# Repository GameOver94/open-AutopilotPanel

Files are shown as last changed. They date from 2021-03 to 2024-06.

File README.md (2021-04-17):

# open AutopilotPanel
A 3D printable autopilot panel for Microsoft Flightsimulator modeled after the Garmin GFC 500

## Features
* 3 Rotary Encoder (HDG / ALT / VS up/down)
* 12 Pushbuttons
* Emulates a standard gamecontroller (no additional software needed)

## Uses Materials
 * 1 [Arduino Pro Micro](https://www.amazon.de/gp/product/B07J2Q3ZD5/ref=ppx_yo_dt_b_asin_title_o03_s00?ie=UTF8&psc=1)
 * 1 [MCP23017 I²C Port Expander](https://eu.mouser.com/ProductDetail/Microchip-Technology/MCP23017-E-SO?qs=usxtMOJb1Rz8hft7vV7YMQ==)
   * Make shure to get the MCP23017-E/SO variant. There are other footpirnts of the chip available. For hand wiring get a bearkout board to make live easier.
 * 3 [Rotary Encoder](https://www.amazon.de/gp/product/B08728PS6N/ref=ppx_yo_dt_b_asin_title_o01_s00?ie=UTF8&psc=1)
 * 12 [Miro Pushbuttons 6x6x5](https://www.amazon.de/gp/product/B07Q1BXV7T/ref=ppx_yo_dt_b_asin_title_o04_s00?ie=UTF8&psc=1)
 * 26 AWG silicone wire
 * Dupont connectors
 * Double sided tape

## Important Note
This is for people who build this before version 1.1.0. The wiring has changed a bit with regard to the previous versions. Mainly the switches of the rotary enocders are now also connected to the MCP23017 and the rotary encoders are now connected to slightly different pins. Therefor the current software won't fully work. I think it's pretty easy to rewire these connections if you want, but I also created a [legacy branch](https://github.com/GameOver94/open-AutopilotPanel/tree/legacy) where you download the old firmware.
## Assembly
The mechaical design was done in Fusion 360. The assemby files can be found in [CAD files](CAD%20files) as .f3z and .step files. STL files for direct 3D Printing can be found on [Thiniverse](https://www.thingiverse.com/thing:4799181).

The electrical design was made with EasyEDA. The files for the PCB can either be found in the folder [PCB files](PCB%20files) or you can order them directly here: https://oshwlab.com/patrick.harrer94/open-autopilot

A [wiring diagram](PCB%20files/Schematic_open-AutopilotPanel.pdf) for the connection between the arduino and the PCB or for manual wiring can be also found in the PCB fiels folder.

### PCB Assembly
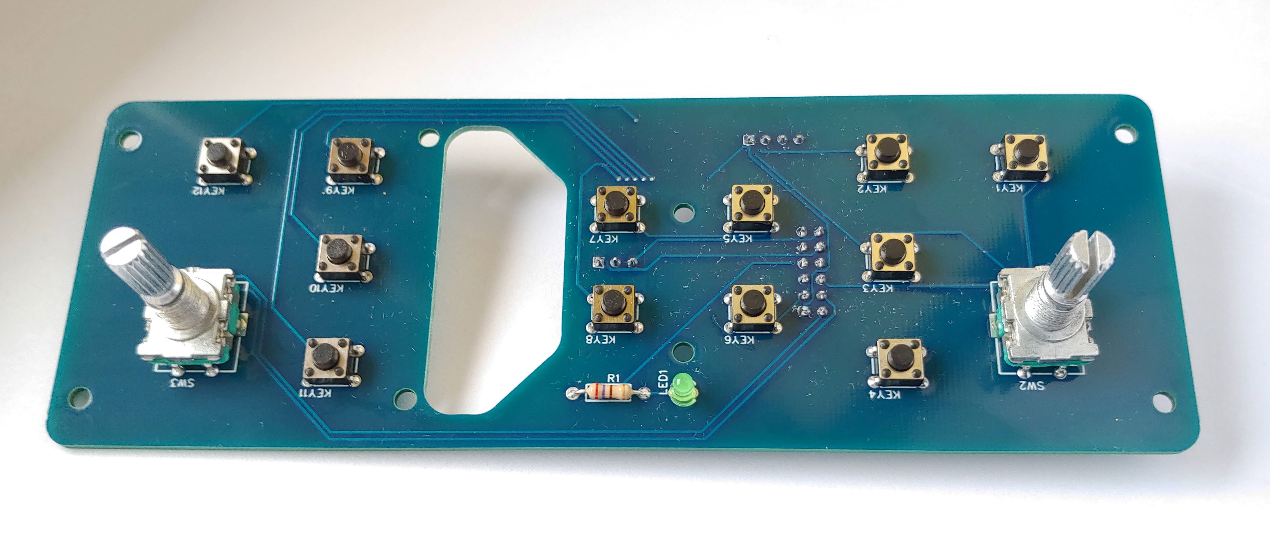
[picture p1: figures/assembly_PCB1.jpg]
image_PCB1

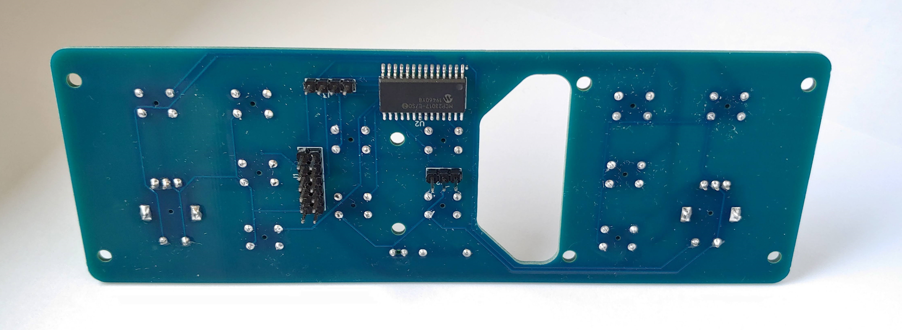
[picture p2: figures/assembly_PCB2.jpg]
image_PCB2

### Electronic Assembly
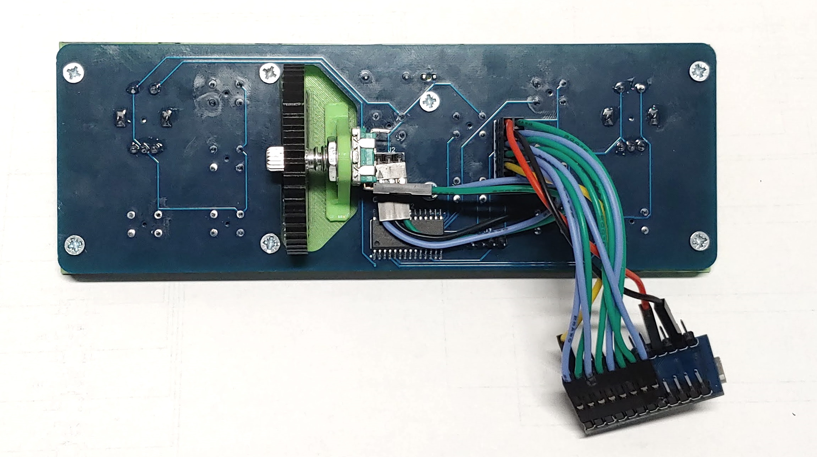
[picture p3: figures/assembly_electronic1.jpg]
image_electornic1

### Whole Assembly
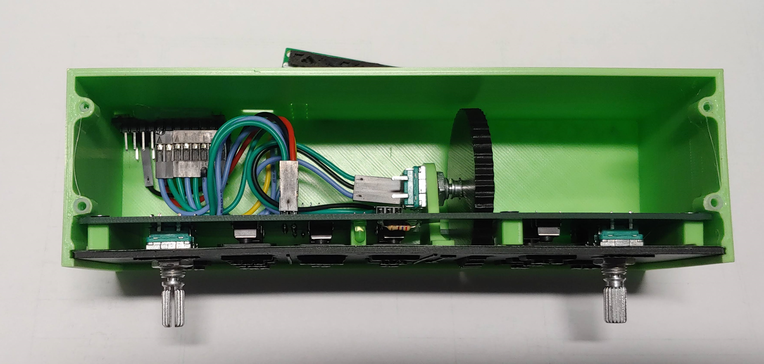
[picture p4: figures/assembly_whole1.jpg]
image_assemby1

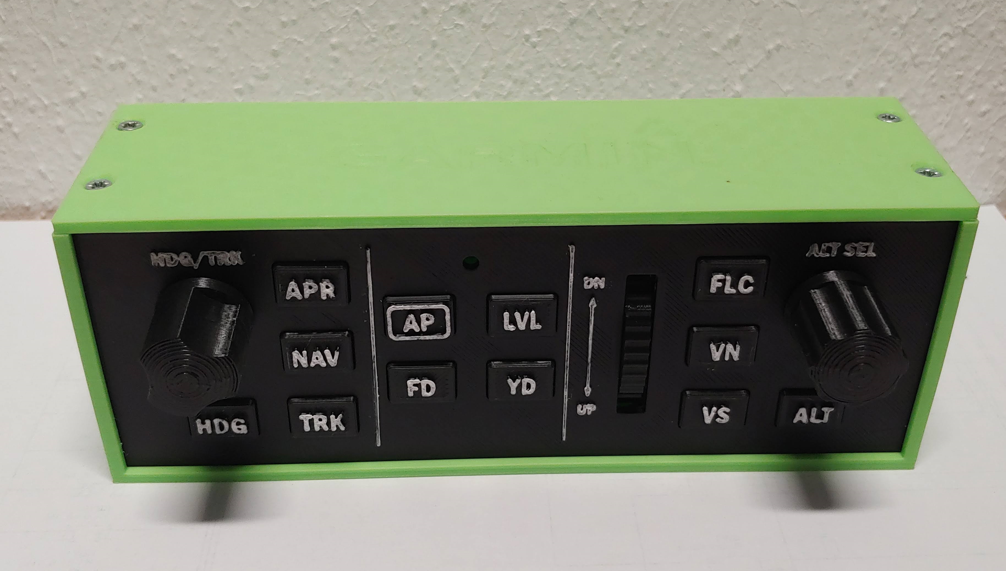
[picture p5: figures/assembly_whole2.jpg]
image_assembly2

### Manual Wireing
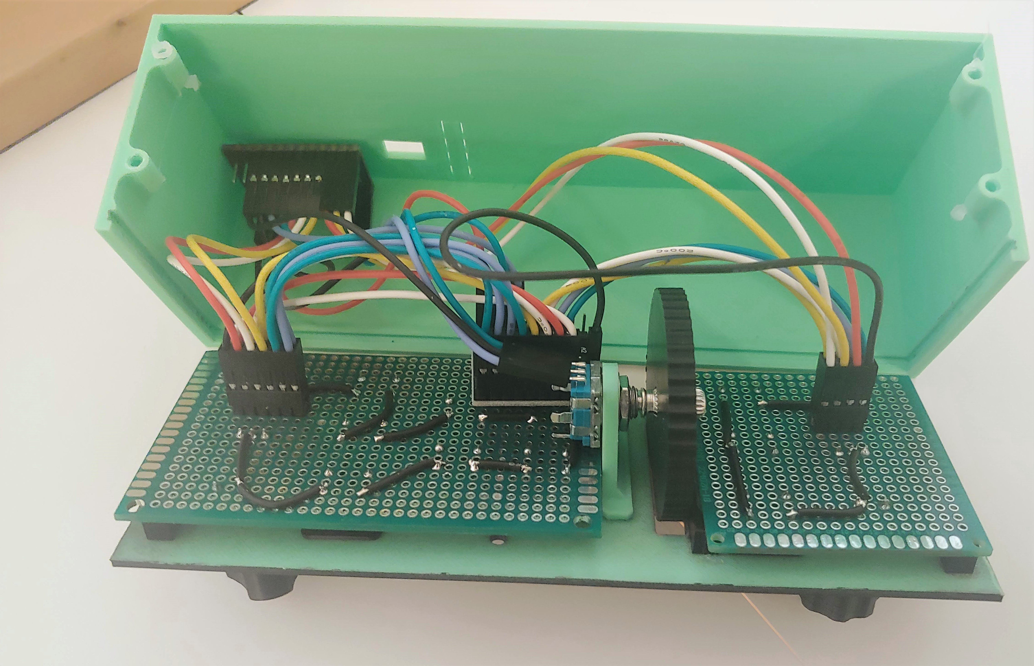
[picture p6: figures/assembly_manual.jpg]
image_assembly3


## Cangelog

### v1.0.0
* Initial release
### v1.0.1
* Tweaks regarding button press timings
### v1.1.0
* Added a PCB design
* Modified software for wiring
  * The buttons in the rotary encoders are now also connected to the MCP23017
  * Added a power LED
## ToDo
* Maybe a version 2 with an added lcd to show AP mode, set altitude usw. (requires software running on the PC)

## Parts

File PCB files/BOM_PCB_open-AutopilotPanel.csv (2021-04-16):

ID | Name | Designator | Footprint | Quantity | Manufacturer Part | Manufacturer | Supplier | Supplier Part | Price | JLCPCB SMD | Paste Type
1 | HDR-M-2.54_2x6 | J1 | HDR-M-2.54_2X6 | 1 |  |  | LCSC | C124388 | 0.0628
2 | HDR-M-2.54_1x3 | J2 | HDR-M-2.54_1X3 | 1 |  |  | LCSC | C180248 | 0.2066
3 | HDR-M-2.54_1x4 | J3 | HDR-M-2.54_1X4 | 1 |  |  | LCSC | C124378 | 0.0261
4 | K4-6×6_TH | KEY1,KEY2,KEY3,KEY4,KEY5,KEY6,KEY7,KEY8,KEY9,KEY10,KEY11,KEY12 | KEY-TH_4P-L6.0-W6.0-P4.50-LS6.5 | 12 | K2-1102DP-E4SW-04 | 韩国韩荣 | LCSC | C136684 | 0.0365
5 | LED-TH-3mm_B | LED1 | LED-TH_BD3.0_BLUE | 1 | 204-10SUBC/S400-A4 | EVERLIGHT(台湾亿光) | LCSC | C86881 | 0.0476
6 | 500Ω | R1 | R_AXIAL-0.4 | 1
7 | Rotary switch | SW2,SW3 | SW7-13.75X11.7X6.5MM | 2 | Rotary switch
8 | MCP23017-E/SO | U2 | SOIC-28_L18.1-W10.3-P1.27-LS10.3-BL | 1 | MCP23017-E/SO | MICROCHIP | LCSC | C47023 | 1.3407 | Yes | recommend

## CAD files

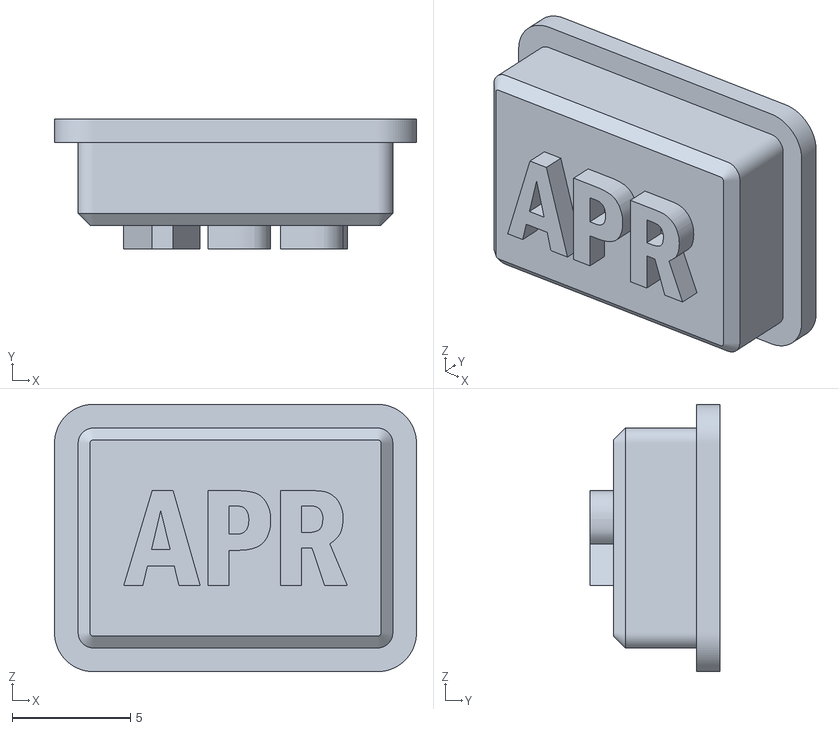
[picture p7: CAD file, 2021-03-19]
3D printing files/Button_Autopilot v12_Körper10_Button.stl
15.3 x 5.50 x 11.3

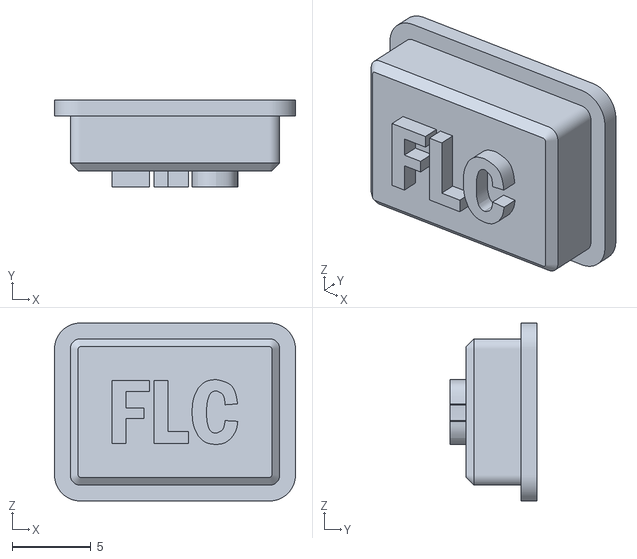
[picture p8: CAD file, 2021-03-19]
3D printing files/Button_Autopilot v12_Körper7_Button.stl
15.3 x 5.50 x 11.3

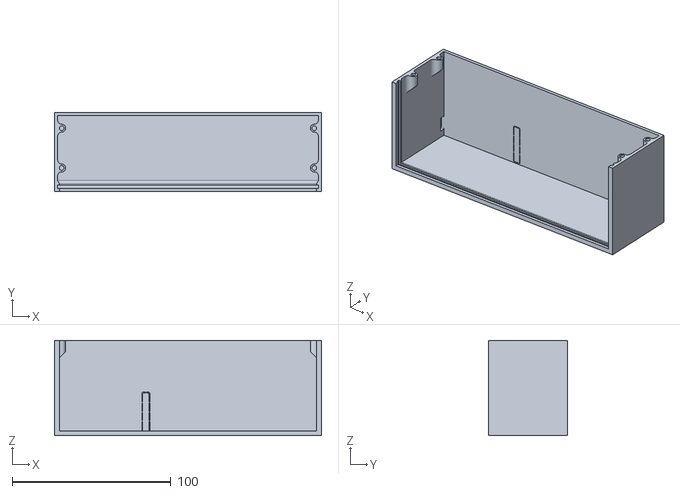
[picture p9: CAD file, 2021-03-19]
3D printing files/Case.stl
168.0 x 50.0 x 60.0

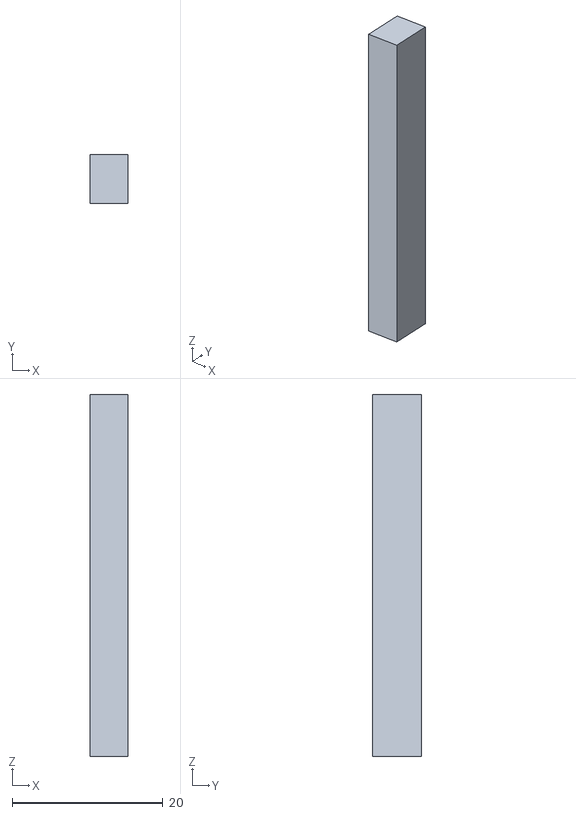
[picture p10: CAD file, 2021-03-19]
3D printing files/PCB Spacer 4.stl
5.00 x 6.50 x 48.0

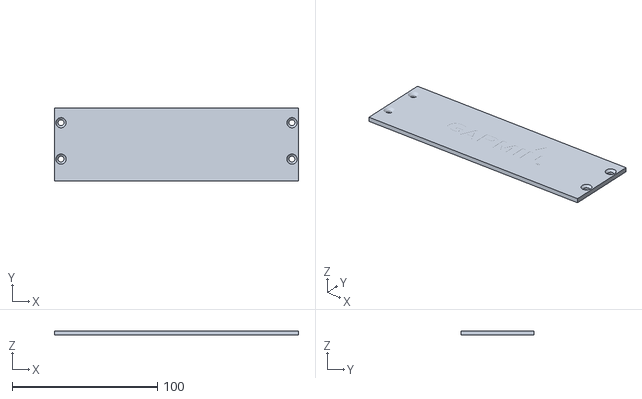
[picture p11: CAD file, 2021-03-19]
3D printing files/Case Cover.stl
168.0 x 50.0 x 3.00

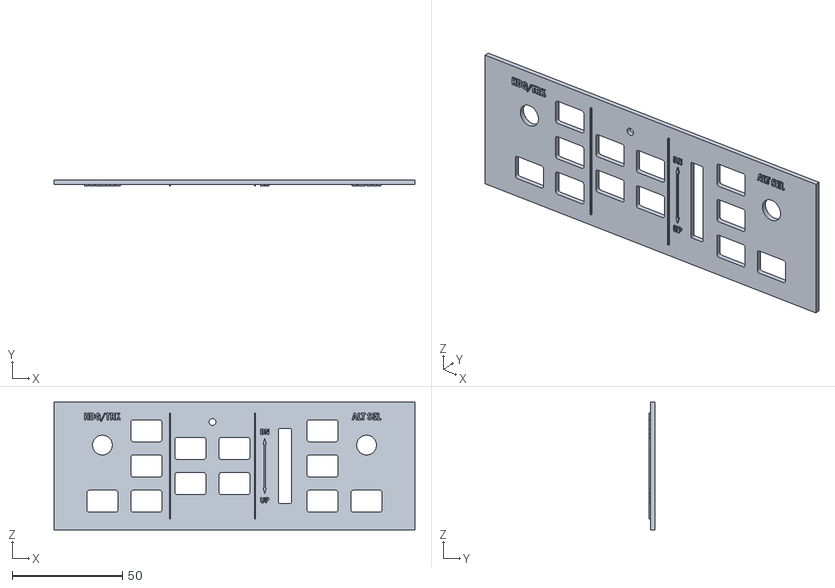
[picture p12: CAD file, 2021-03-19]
3D printing files/Faceplate.stl
164.0 x 2.60 x 58.0

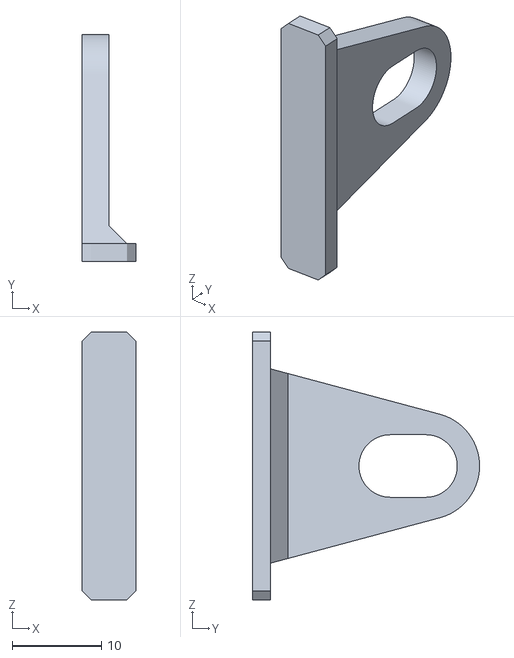
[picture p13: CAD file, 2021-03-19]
3D printing files/Wheel Holder.stl
6.00 x 25.4 x 30.0

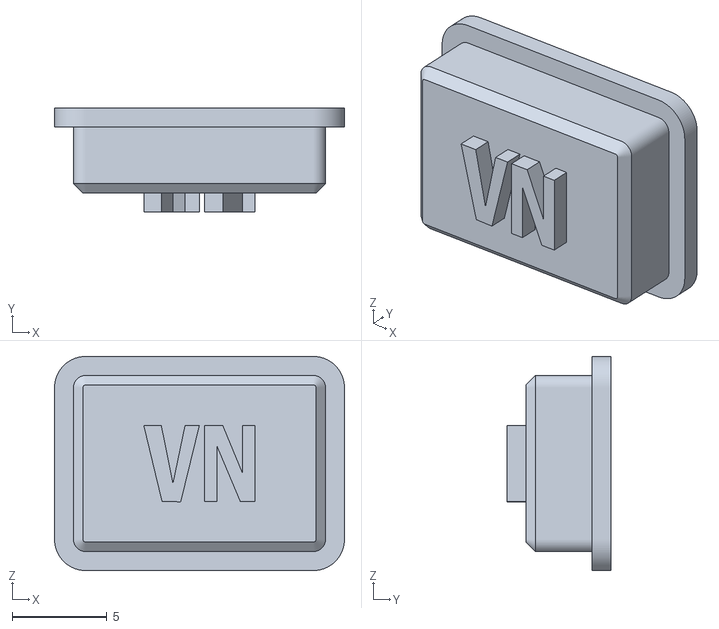
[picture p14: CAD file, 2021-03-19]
3D printing files/Button_Autopilot v12_Körper1_Button.stl
15.3 x 5.50 x 11.3

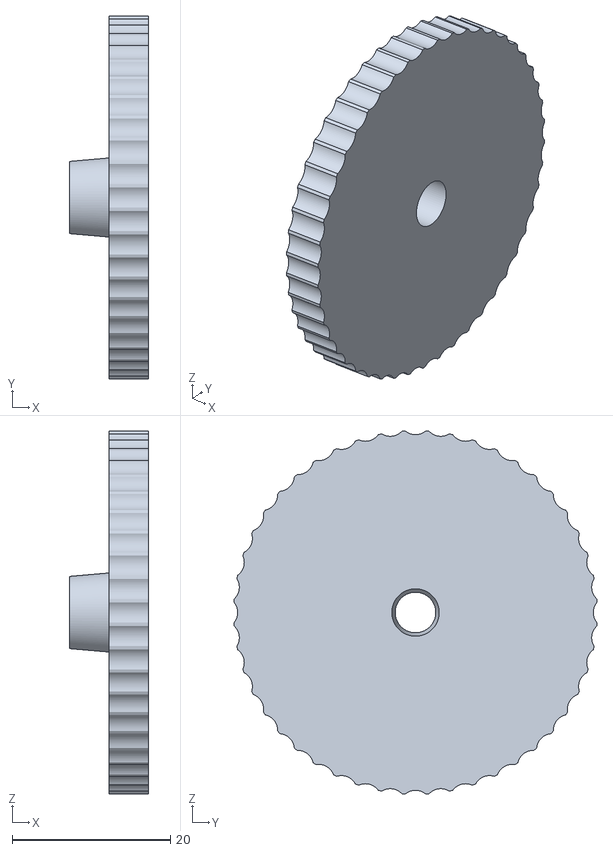
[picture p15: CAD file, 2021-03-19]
3D printing files/Wheel.stl
10.0 x 45.9 x 45.9

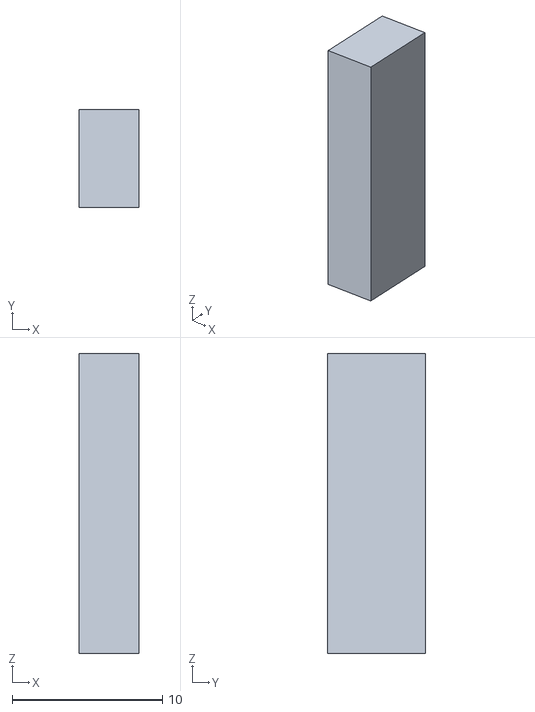
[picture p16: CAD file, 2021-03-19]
3D printing files/PCB Spacer 2.stl
4.00 x 6.50 x 20.0

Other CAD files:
3D printing files/Button_Autopilot v12_Körper9_Button.stl
3D printing files/PCB Spacer 1.stl
3D printing files/Button_Autopilot v12_Körper12_Button.stl
3D printing files/Button_Autopilot v12_Körper6_Button.stl
3D printing files/Button_Autopilot v12_Körper2_Button.stl
3D printing files/PCB Spacer 3.stl
3D printing files/Button_Autopilot v12_Körper3_Button.stl
3D printing files/Button_Autopilot v12_Körper11_Button.stl
3D printing files/Button_Autopilot v12_Körper4_Button.stl
3D printing files/Button_Autopilot v12_Körper5_Button.stl
3D printing files/Button_Autopilot v12_Körper8_Button.stl
3D printing files/Knob 3 Slot.stl
3D printing files/Knob 8 Slot.stl
CAD files/Autopilot v21.f3z

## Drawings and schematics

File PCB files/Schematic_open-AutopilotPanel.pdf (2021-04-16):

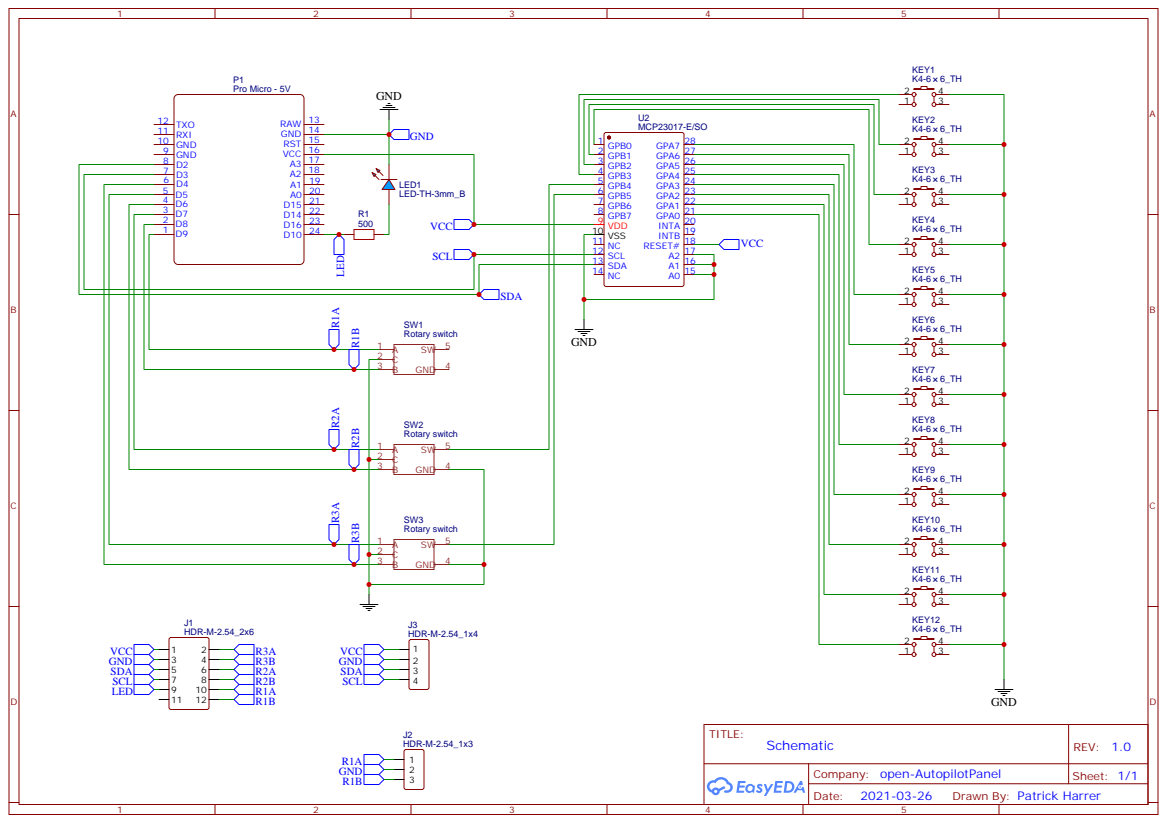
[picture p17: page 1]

Drawn By: Patrick Harrer

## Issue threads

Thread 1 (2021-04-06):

suggestion: led indication of ap mode

medoh300, 2021-04-06:
as on the real thing , one could have a led indicating which AP mode is selected :

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

a video of the real thing in action:

https://www.youtube.com/watch?v=TLRn8gpOxv0

GameOver94, 2021-04-07:
I think currently it won't be possible because it will get synchronized. To do this an application has to run on the PC and hook into the flight sim and send back state of autopilot.

Additionally this will almost double the pins needed. I'm currently designing a PCB and to fit a second MCP23017 the push buttons and LEDs have to be surface mount components.

In the future I'm planing a version 2 which communicates via SimConnect. There I might consider this again but this will take a while.

medoh300, 2021-04-07:
would it be possible with mobiflight and logic for lights maybe ?

GameOver94, 2021-04-08:
I'm not very familiar with mobiflight but I think it might be possible but as far as I can tell the mobiflight firmware doesn't support the MCP23017 so the firmware has to be modified.

Closed 2021-06-22.

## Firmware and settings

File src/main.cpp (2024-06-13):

#include <Arduino.h>
#include <Wire.h>
#include <Adafruit_MCP23X17.h>
#include <Rotary.h>
#include <Joystick.h>

// Pin Mapping --------------------------------------------------------------------------------
#define HDG 11    // Key 1
#define TRK 10    // Key 2
#define NAV 9     // Key 3
#define APR 8     // Key 4
#define FD 7      // Key 5
#define AP 6      // Key 6
#define YD 5      // Key 7
#define LVL 4     // Key 8
#define VS 3      // Key 9
#define VN 2      // Key 10
#define FLC 1     // Key 11
#define ALT 0     // Key 12

#define rotHDGButton 12     // SW2
#define rotALTButton 13     // SW3

#define rotHDG_A 6     // SW2
#define rotHDG_B 7     // SW2

#define rotALT_A 5     // SW3
#define rotALT_B 4     // SW3

#define rotVS_A 8 // SW1
#define rotVS_B 9 // SW1

#define pwrLED 10

// Function prototypes ------------------------------------------------------------------------
void pollButton();
void pollRotary();
void updateButton(bool buttonState[16]);
void release();

// Setup the joystick library -----------------------------------------------------------------
/* Create the Joystick */
Joystick_ Joystick;

/* Joystick Button Mapping
rotary HDG right      0
rotary HDG left       1
rotary ALT right      2
rotary ALT left       3
rotary VS up          4
rotary VS down        5

button ALT            6
button AP             12
button APR            14
button FD             13
button FLC            7
button HDG            17
button LVL            10
button NAV            15
button TRK            16
button VN             8
button VS             9
button YD             11
rotary ALT            19
rotary HDG            18
*/

// Setup the MCP23017 GPIO expander -----------------------------------------------------------
Adafruit_MCP23X17 mcp;

// Setup rotary encoder------------------------------------------------------------------------
Rotary rotHDG = Rotary(rotHDG_A, rotHDG_B);
Rotary rotALT = Rotary(rotALT_A, rotALT_B);
Rotary rotVS = Rotary(rotVS_A, rotVS_B);

// Global variables
const uint8_t numRotary = 6;            // For each rotary encoder two (one per direction)
unsigned long releaseTime[numRotary];    // Stores the release time for the buttons (rotary encoder).
bool rotaryPressed[numRotary] = {false}; // Stores the button state for the rotary encoder (gets automatically reset)
const int rotaryHoldTime = 50;           // time a Button is held down in ms (rotary encoder)
const int buttonHoldTime = 100;          // time a Button is held down in ms (buttons)
uint16_t lastButtonState = 0;            // Stores the button state for the MCP23017 Port Expander

void setup()
{
  Serial.begin(115200);
  Serial.println("open AutopilotPanel v1.x");

  // Initialize Joystick Library
  Joystick.begin();

  // Initialize the MCP23017
  mcp.begin_I2C(); // use default address 0x20

  for (int i = 0; i <= 15; i++)
  {
    mcp.pinMode(i, INPUT_PULLUP); // set pin as input with internal pull-up
  }

  // Initialize the Rotary Encoder
  // No need to call begin

  // Switch on power LED
  pinMode(pwrLED, OUTPUT);
  digitalWrite(pwrLED, HIGH);
}

void loop()
{
  pollRotary();
  pollButton();
  release();
}

// Polling the MCPs to check for changes
void pollButton()
{
  // We could also read each pin separately; however, that will cause an I2C transfer for each pin.
  // It's faster to read the whole register and decode the register.
  uint32_t newButtonState = mcp.readGPIOAB();

  if (lastButtonState != newButtonState)
  {
    bool buttonState[16];
    lastButtonState = newButtonState;
    uint16_t mask = 1;

    for (uint8_t i = 0; i <= 15; i++) // binary masking starting at the least significant bit
    {
      buttonState[i] = newButtonState & (mask << i) ? 1 : 0;
    }

    updateButton(buttonState);
  }
}

// Update the Joystick with the input from the Buttons connected to the MCP
void updateButton(bool buttonState[16])
{
  for (uint8_t i = 0; i < 15; i++)
  {
    Joystick.setButton(i + 6, !buttonState[i]);
  }
}

// Evaluates the rotary encoders and updates the Joystick
void pollRotary()
{
  unsigned char resultHDG = rotHDG.process();
  if (resultHDG)
  {
    if (!rotaryPressed[0 + resultHDG / 16 - 1]) // rejects input when button wasn't released before
    {
      Joystick.setButton(0 + resultHDG / 16 - 1, 1);
      releaseTime[0 + resultHDG / 16 - 1] = millis() + rotaryHoldTime;
      rotaryPressed[0 + resultHDG / 16 - 1] = true;
    }
  }

  unsigned char resultALT = rotALT.process();
  if (resultALT)
  {
    if (!rotaryPressed[2 + resultALT / 16 - 1]) // rejects input when button wasn't released before
    {
      Joystick.setButton(2 + resultALT / 16 - 1, 1);
      releaseTime[2 + resultALT / 16 - 1] = millis() + rotaryHoldTime;
      rotaryPressed[2 + resultALT / 16 - 1] = true;
    }
  }

  unsigned char resultVS = rotVS.process();
  if (resultVS)
  {
    if (!rotaryPressed[4 + resultVS / 16 - 1]) // rejects input when button wasn't released before
    {
      Joystick.setButton(4 + resultVS / 16 - 1, 1);
      releaseTime[4 + resultVS / 16 - 1] = millis() + rotaryHoldTime;
      rotaryPressed[4 + resultVS / 16 - 1] = true;
    }
  }
}

// Release buttons of the Joystick triggered by the Rotary Encoder
void release()
{
  for (int i = 0; i < numRotary; i++)
  {
    if (releaseTime[i] < millis())
    {
      Joystick.setButton(i, 0);
      releaseTime[i] = millis() + rotaryHoldTime;
      if (rotaryPressed[i])
      {
        rotaryPressed[i] = false;
      }
    }
  }
}

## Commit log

2021-03-19 Initial release
    [Autopilot v12.f3z, Button_Autopilot v12_Körper10_Button.stl, Button_Autopilot v12_Körper11_Button.stl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]
2021-03-21 Improved timings for rotary encoder
    Windows drops some of the inpus when the encoders are turned to fast
2021-03-26 Added wiring diagram
2021-04-06 Updated Schematic
2021-04-16 Updated CAD files
    [Autopilot v12.f3z, Autopilot v19.f3z]
2021-04-16 Added PCB files
    [BOM_PCB_open-AutopilotPanel.csv]
2021-04-16 Updated firmware to suport the PCB version
2021-04-16 Updated button mapping
2021-04-17 Added power LED
2024-05-22 Update main.cpp
    Fixed potential buffer overflow in updateButton.
    Adafruit MCP23017 Arduino Library 2.3.2 required small changes.
    A little bit of cleanup.
    [main.cpp]
